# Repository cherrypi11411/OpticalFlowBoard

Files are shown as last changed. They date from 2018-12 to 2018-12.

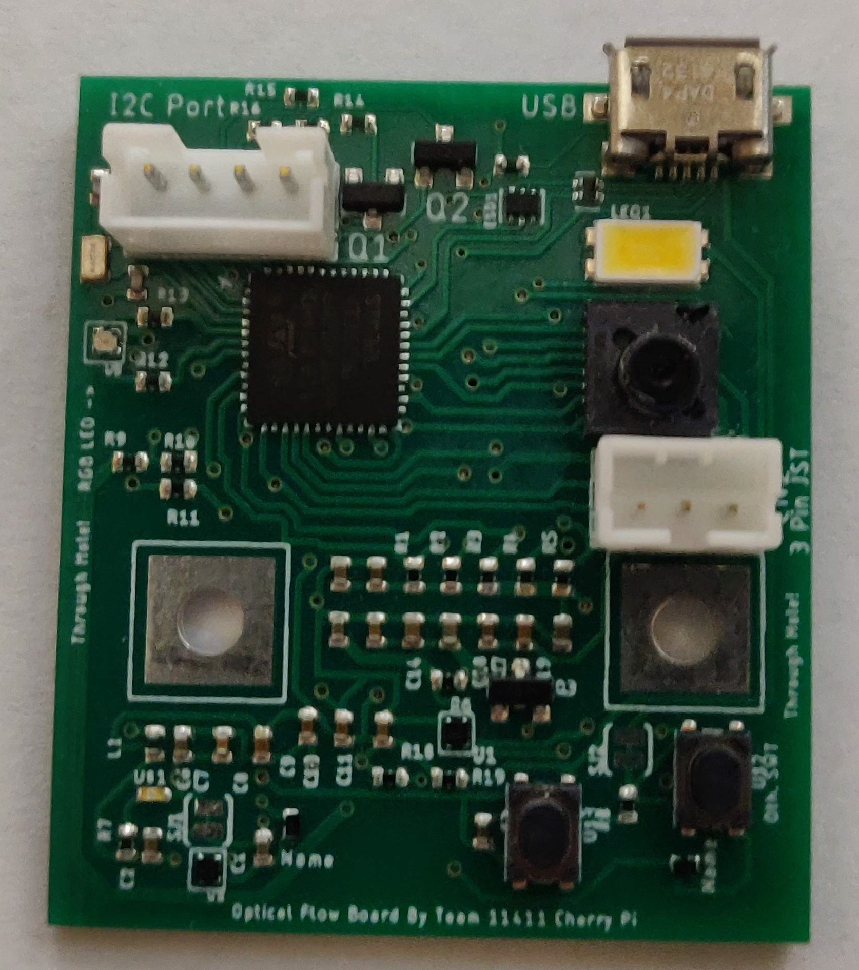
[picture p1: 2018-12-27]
documentation/Board-1-Front.jpg

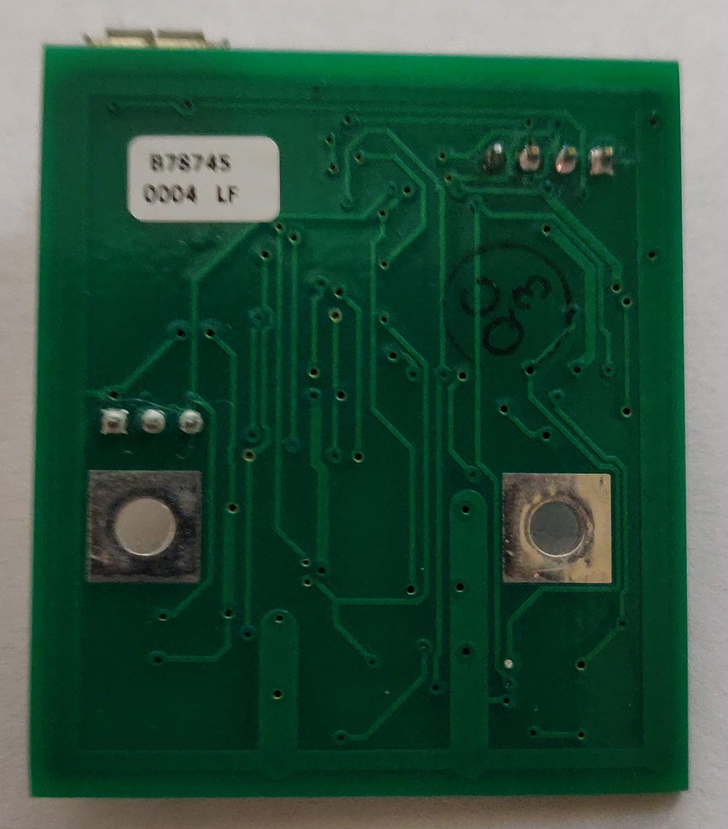
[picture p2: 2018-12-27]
documentation/Board-2-Back.jpg

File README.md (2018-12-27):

# OpticalFlowBoard
Hardware design and source code for OpticalFlowBoard

We are [Team 11411 Cherry Pi](https://cherrypi.egoslike.us/). We are a FIRST Tech Challenge (FTC) robotics team based in San Diego, California. Over the past several years, one of the biggest challenges we see with the robots is how to determine where the robot is accurately. During our journey, we discovered many ways to approach this problem. One that looked especially promising is using an optical flow sensor similar to what is available for many optical mice. One such product is produced by PixArt, the [PMW-3901 chip](http://www.pixart.com.tw/product_data.asp?product_id=168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).

This chip is especially attractive as it is designed for robotics/drone usage with the sensor at a distance from the surface. Many mice sensors require a very close distance to surfaces to operate properly. A big disadvantage of this chip for our purposes is that it uses SPI for communication. Within FTC, SPI is not an option for sensor integration. Instead, analog, digital or I2C sensors are allowed.

We then experimented with translating SPI to I2C and created a prototype using these two products:
* The [Butterfly Board](https://www.tindie.com/products/TleraCorp/butterfly-stm32l433-development-board/)
* The [PMW-3901 Sensor Board](https://www.tindie.com/products/onehorse/pmw3901-optical-flow-sensor/)

These products are open source designs so inspired by those designs, some of our students created a new design combining the two boards together into a unified product. We then investigated getting the boards manufactured and eventually got in contact with [Advanced Assembly](http://www.aapcb.com/). When we described our project to them and that this board was being designed and programmed by middle and high school age kids, they were excited to help us out and graciously provided feedback on our design as well as offering to manufacture an initial run of boards for prototyping for free to us.

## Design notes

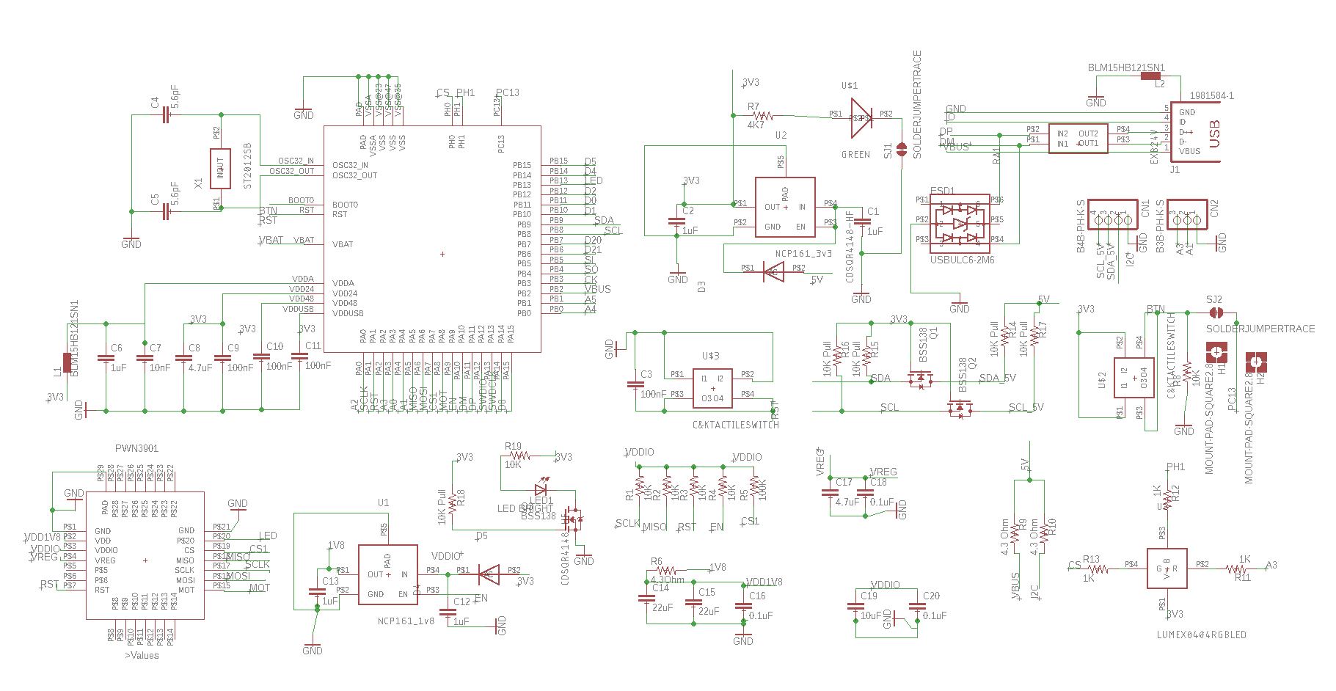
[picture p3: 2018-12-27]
documentation/Schematic.png

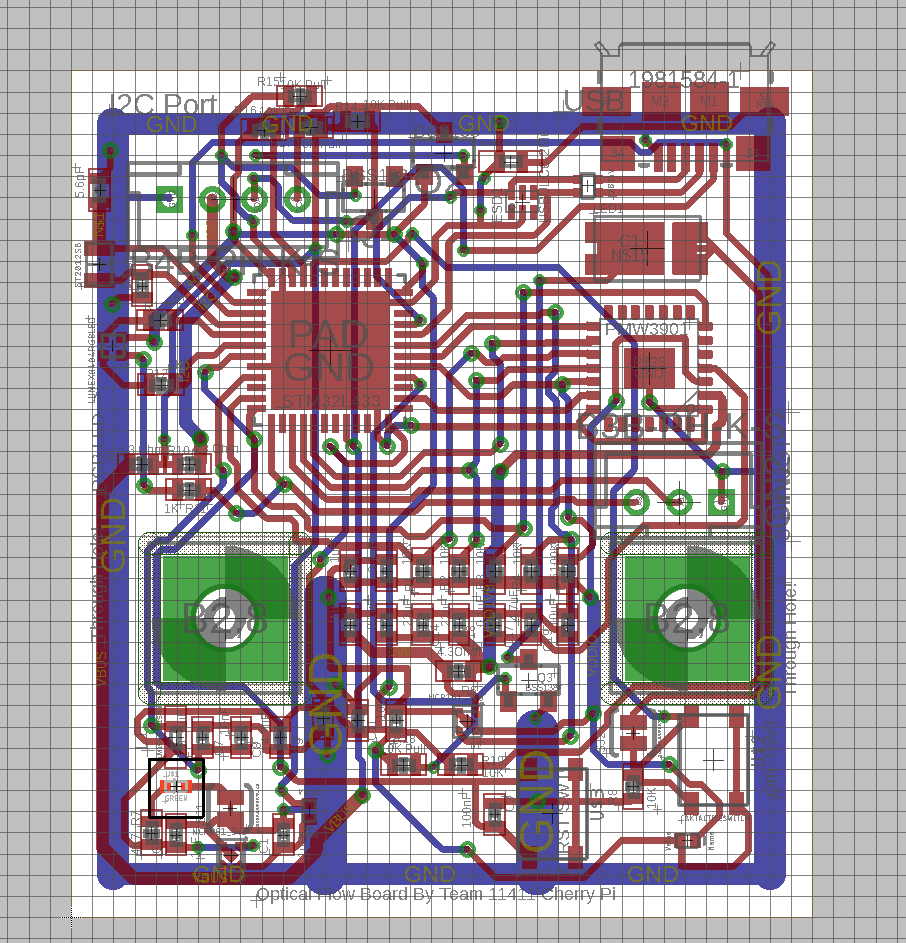
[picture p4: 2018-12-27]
documentation/Layout.png

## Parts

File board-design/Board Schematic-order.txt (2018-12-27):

Exported from EAGLE with DesignLink
Parts List:

Quantity	Value	Package	Order code	Manufacturer	Manuf. Code	Availability	Price (from)	Description
5        	1uF		0402-CAP	46P6240		MC0805B104K500A5.08MM	589108	0.085	MULTICOMP - MC0805B104K500A5.08MM - CERAMIC CAPACITOR 0.1UF, 50V, X7R, 10%, RADIAL
4			100nF	0402-CAP	URL: https://www.mouser.com/ProductDetail/KEMET/C0402C104K4RACAUTO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
2			5.6pF	0402-CAP	URL: https://www.mouser.com/ProductDetail/KEMET/C0402C569D5GACAUTO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
1			10uF	0402-CAP	53W3840		EEE-1VA100WR	45488	0.081	PANASONIC ELECTRONIC COMPONENTS - EEE-1VA100WR - ALUMINUM ELECTROLYTIC CAPACITOR, 10UF, 35V, 20%, SMD
1			10 nF	0402-CAP	URL: https://www.mouser.com/ProductDetail/KEMET/C0402C103K4RALTU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
2			4.7uF	0402-CAP	27X7920		293D475X9016B2TE3	20000	0.137	VISHAY - 293D475X9016B2TE3 - TANTALUM CAPACITOR, 4.7UF 16V 2.9 OHM 10%, 3528-21, FULL REEL
2			22uF	0402-CAP	53W3820		EEE-1HA220WP	5254	0.133	PANASONIC ELECTRONIC COMPONENTS - EEE-1HA220WP - ALUMINUM ELECTROLYTIC CAPACITOR, 22UF, 50V, 20%, SMD
3			0.1uF	0402-CAP	46P6240		MC0805B104K500A5.08MM	589108	0.085	MULTICOMP - MC0805B104K500A5.08MM - CERAMIC CAPACITOR 0.1UF, 50V, X7R, 10%, RADIAL
1			B4B-PH-K-S	37K9958	FARNELL	B4B-PH-K-S(LF)(SN)	4851	0.115	JST (JAPAN SOLDERLESS TERMINALS) - B4B-PH-K-S(LF)(SN) - WIRE TO BOARD CONNECTOR, HEADER, 4 POSITION, 2MM
2			CDSQR4148-HF	CDSQR4148-HF	URL:			https://www.digikey.com/product-detail/en/comchip-technology/CDSQR4148-HF/641-1677-1-ND/5147314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	
1			USBULC6-2M6				URL:https://www.digikey.com/product-detail/en/stmicroelectronics/USBULC6-2M6/497-7044-1-ND/1880382
2			MOUNT-PAD-SQUARE2.8	2,8-PAD-SQUARE	unknown					N/A
1			1981584-1	1981584-1	74M6302		1981584-1	13	1.08	AMP - TE CONNECTIVITY - 1981584-1 - MICRO USB CONN, 2.0 TYPE AB, RCPT, SMT
2			BLM15HB121SN1	0402	73M9043		BLM15HB121SN1D	0	0.061	MURATA - BLM15HB121SN1D - FERRITE BEAD, 0.7OHM, 300mA, 0402
1			PMW3901	COB	unknown		Provided			
6			10K	0402-RES	01X1282		ERA-3AEB103V	15000	0.038	PANASONIC ELECTRONIC COMPONENTS - ERA-3AEB103V - RES, METAL FILM, 10K, 0.1%, 0.1W, 0603, REEL
1			100K	0402-RES	01P2083		MCTF0805BTC1003	7622	0.098	MULTICOMP - MCTF0805BTC1003 - RES, THIN FILM, 100K, 0.1%, 0.1W, 0805
3			0402RES.KW	0402-RES	13AC1056		CRCW04024R30FKED	9980	0.018	VISHAY - CRCW04024R30FKED - RES, AEC-Q200, THICK FILM, 4R3, 1%, 0402
1			4K7	0402-RES	90W3200		ERJ-3EKF4701V	65000	0.0080	PANASONIC ELECTRONIC COMPONENTS - ERJ-3EKF4701V - RES, THICK FILM, 4K7, 1%, 0.1W, 0603, REEL
3			1K	URL: https://www.mouser.com/ProductDetail/Panasonic/ERJ-S02F1001X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
1			EXB24V	EXB24V	52W4404		EXB-24V100JX	0	0.01	PANASONIC ELECTRONIC COMPONENTS - EXB-24V100JX - 10ohm, 7 inch reel
2			SOLDERJUMPERTRACE	SJ_2S-TRACE	unknown		N/A			
1			GREEN	0402LED	30K1434	DIALIGHT	551-0207F	46775	0.361	DIALIGHT - 551-0207F - INDICATOR, LED PCB, 3MM, GREEN, 2.1V
1			LUMEX RGB LED	URL: https://www.mouser.com/new/lumex/lumexrgb0404/
2			C&KTACTILESWITCH	C&KTACTILESWITCH	URL:					https://www.mouser.com/ProductDetail/CK/PTS810SJS250SMTRLFS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
1			STM32L433	QFN50P700X700X60-49N	24AC5432		STM32L433CCU6	624	3.57	STMICROELECTRONICS - STM32L433CCU6 - MCU, ARM CORTEX-M4, 80MHZ, QFN-48 Provided
1			NCP161	NCP161	42AC1775		NCP161AMX330TBG	5948	0.111	ON SEMICONDUCTOR - NCP161AMX330TBG - LDO, FIXED, 3.3V, 0.45A, XDFN-4
1			NCP161	NCP161			NCP161AMX180TBG	5948	0.111	ON SEMICONDUCTOR - NCP161AMX180TBG - LDO, FIXED, 1.8V, 0.45A, XDFN-4
1			ST2012SB	ST2012SB	38Y8580		ST2012SB32768H5HPWAA	910	0.553	AVX - ST2012SB32768H5HPWAA - CRYSTAL, 32.768KHZ, 12.5PF, 2 X 1.2MM
1			B3B-PH-K-S URL: https://www.digikey.com/product-detail/en/jst-sales-america-inc/B3B-PH-K-S-LF-SN/455-1705-ND/926612
5			PRT-14491 (10k Pull) URL: https://www.robotshop.com/en/resistor-10k-ohm-1-4-watt-pth-20pk.html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
3			BSS138 URL: https://www.digikey.com/product-detail/en/fairchild-semiconductor/BSS138/BSS138CT-ND/244294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
1			LED BRIGHT URL: https://www.digikey.com/product-detail/en/samsung-semiconductor-inc/SPMWHT541ML5XAR0S6/1510-2182-1-ND/6569493

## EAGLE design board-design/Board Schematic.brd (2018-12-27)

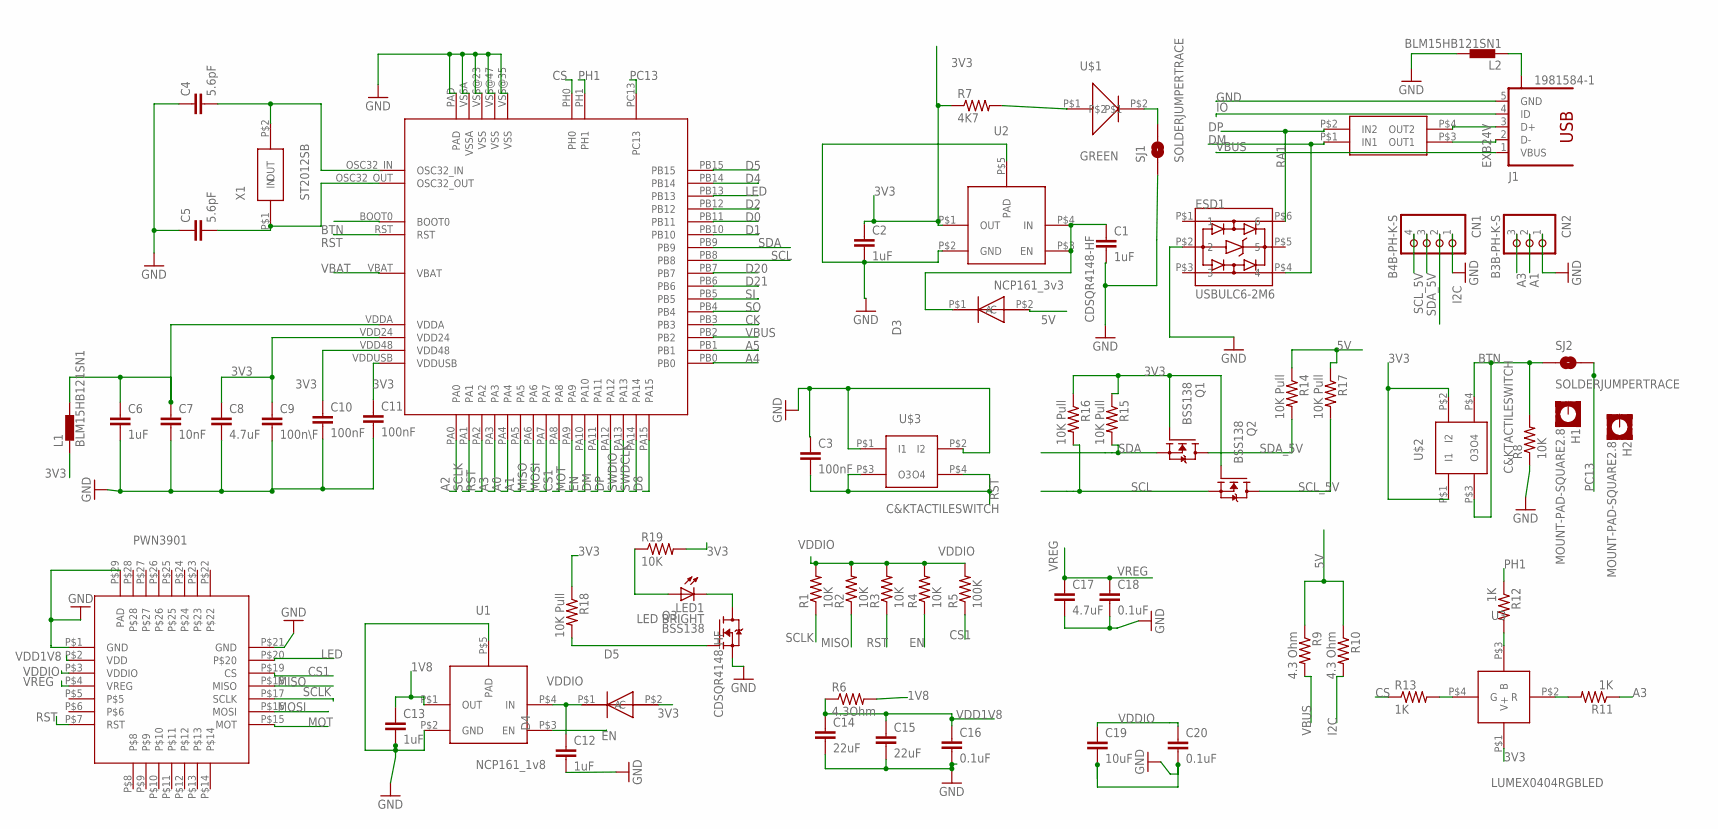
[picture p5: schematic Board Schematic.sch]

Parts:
C1, C2, C6, C12, C13: 1uF; 0402-CAP
C3, C10, C11: 100nF; 0402-CAP
C4, C5: 5.6pF; 0402-CAP
C7: 10nF; 0402-CAP
C8, C17: 4.7uF; 0402-CAP
C9: 100n\F; 0402-CAP
C14, C15: 22uF; 0402-CAP
C16, C18, C20: 0.1uF; 0402-CAP
C19: 10uF; 0402-CAP
CN1: B4B-PH-K-S
CN2: B3B-PH-K-S
D3, D4: CDSQR4148-HF
ESD1: USBULC6-2M6; UQFN6
H1, H2: MOUNT-PAD-SQUARE2.8; 2,8-PAD-SQUARE
J1: 1981584-1
L1, L2: BLM15HB121SN1; 0402
LED1: LED BRIGHT; LM561C
PWN3901: COB_PMW3901; COB
Q1, Q2, Q3: BSS138; SOT23
R1, R2, R3, R4, R8, R19: 10K; 0402-RES
R5: 100K; 0402-RES
R6: 4.3Ohm; 0402-RES
R7: 4K7; 0402-RES
R9, R10: 4.3 Ohm; 0402-RES
R11, R12, R13: 1K; 0402-RES
R14, R15, R16, R17, R18: 10K Pull; 0402-RES
RA1: EXB24V
SJ1, SJ2: SOLDERJUMPERTRACE; SJ_2S-TRACE
U1: NCP161_1v8; NCP161
U2: NCP161_3v3; NCP161
U3: LUMEX0404RGBLED; LX0404
U$1: GREEN; 0402LED
U$2, U$3: C&KTACTILESWITCH
U$4: STM32L433; QFN50P700X700X60-49N
X1: ST2012SB

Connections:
1V8: C13.1, R6.2, U1.P$1 (OUT)
3V3: C2.1, C8.1, C9.1, C10.1, C11.1, D4.P$2 (A), L1.1, Q1.1 (G), Q2.1 (G), R7.1, R15.1, R16.1, R18.1, R19.2, U2.P$1 (OUT), U3.P$1 (V+), U$2.P$1 (I1), U$2.P$2 (I2), U$4.VDD24, U$4.VDD48, U$4.VDDUSB
5V: D3.P$2 (A), R9.1, R10.1, R14.1, R17.1
A0: U$4.PA4
A1: CN2.2, U$4.PA5
A2: U$4.PA0
A3: CN2.3, R11.1, U$4.PA3
A4: U$4.PB0
A5: U$4.PB1
BTN: R8.2, SJ2.1, U$2.P$3 (O3), U$2.P$4 (O4), U$4.BOOT0
CK: U$4.PB3
CS: R13.1, U$4.PH0
CS1: PWN3901.P$19 (CS), R5.1, U$4.PA8
D0: U$4.PB11
D1: U$4.PB10
D2: U$4.PB12
D4: U$4.PB14
D5: Q3.1 (G), R18.2, U$4.PB15
D8: U$4.PA15
D20: U$4.PB7
D21: U$4.PB6
DM: ESD1.P$4 (4), RA1.P$1 (IN1), U$4.PA11
DP: ESD1.P$6 (6), RA1.P$2 (IN2), U$4.PA12
EN: R4.1, U1.P$3 (EN), U$4.PA10
GND: C1.2, C2.2, C3.1, C4.1, C5.1, C6.2, C7.2, C8.2, C9.2, C10.2, C11.2, C12.2, C13.2, C14.2, C15.2, C16.2, C17.2, C18.2, C19.2, C20.2, CN1.1, CN2.1, ESD1.P$2 (2), J1.5 (GND), L2.2, PWN3901.P$1 (GND), PWN3901.P$21 (GND), PWN3901.P$29 (PAD), Q3.2 (S), R8.1, SJ1.1, U1.P$2 (GND), U1.P$5 (PAD), U2.P$2 (GND), U2.P$5 (PAD), U$3.P$1 (I1), U$3.P$2 (I2), U$4.PAD, U$4.VSS@23 (VSS), U$4.VSS@35 (VSS), U$4.VSS@47 (VSS), U$4.VSSA
I2C: CN1.2, R10.2
IO: J1.4 (ID)
LED: PWN3901.P$20, U$4.PB13
MISO: PWN3901.P$18 (MISO), R2.1, U$4.PA6
MOSI: PWN3901.P$16 (MOSI), U$4.PA7
MOT: PWN3901.P$15 (MOT), U$4.PA9
unnamed: C4.2, U$4.OSC32_IN, X1.P$2 (OUT)
unnamed: C6.1, C7.1, L1.2, U$4.VDDA
unnamed: R13.2, U3.P$4 (G)
unnamed: C5.2, U$4.OSC32_OUT, X1.P$1 (IN)
unnamed: R12.2, U3.P$3 (B)
unnamed: R11.2, U3.P$2 (R)
unnamed: J1.S1, L2.1
unnamed: J1.3 (D+), RA1.P$4 (OUT2)
unnamed: J1.2 (D-), RA1.P$3 (OUT1)
unnamed: R7.2, U$1.P$1
unnamed: SJ1.2, U$1.P$2
unnamed: LED1.A1 (A), LED1.A2 (A), LED1.A3 (A), R19.1
unnamed: LED1.C1 (C), LED1.C2 (C), LED1.C3 (C), Q3.3 (D)
unnamed: C1.1, D3.P$1 (C), U2.P$3 (EN), U2.P$4 (IN)
PC13: SJ2.2, U$4.PC13
PH1: R12.1, U$4.PH1
RST: C3.2, PWN3901.P$7 (RST), R3.1, U$3.P$3 (O3), U$3.P$4 (O4), U$4.PA2, U$4.RST
SCL: Q2.2 (S), R16.2, U$4.PB8
SCLK: PWN3901.P$17 (SCLK), R1.1, U$4.PA1
SCL_5V: CN1.4, Q2.3 (D), R17.2
SDA: Q1.2 (S), R15.2, U$4.PB9
SDA_5V: CN1.3, Q1.3 (D), R14.2
SI: U$4.PB5
SO: U$4.PB4
SWDCLK: U$4.PA14
SWDIO: U$4.PA13
VBAT: U$4.VBAT
VBUS: J1.1 (VBUS), R9.2, U$4.PB2
VDD1V8: C14.1, C15.1, C16.1, PWN3901.P$2 (VDD), R6.1
VDDIO: C12.1, C19.1, C20.1, D4.P$1 (C), PWN3901.P$3 (VDDIO), R1.2, R2.2, R3.2, R4.2, R5.2, U1.P$4 (IN)
VREG: C17.1, C18.1, PWN3901.P$4 (VREG)

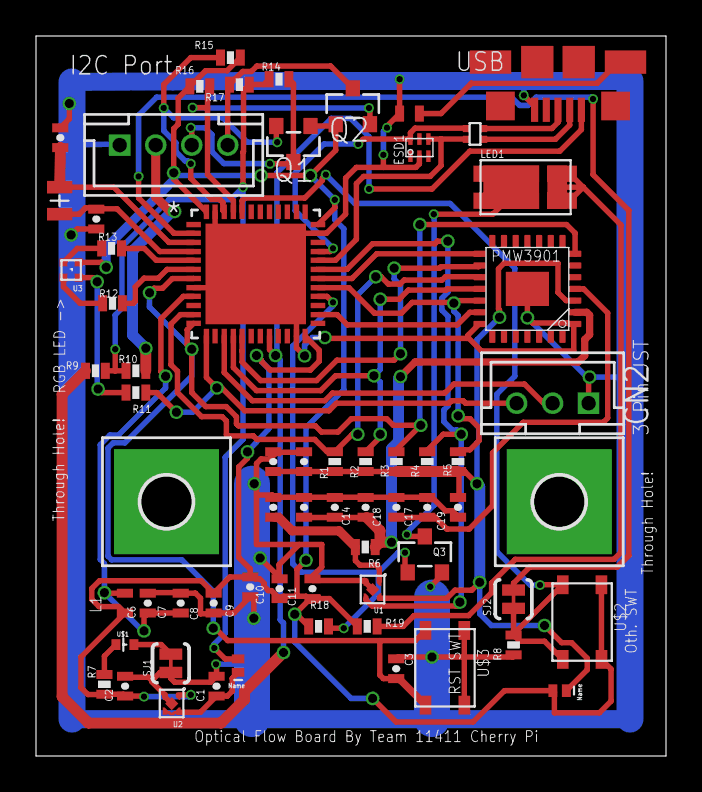
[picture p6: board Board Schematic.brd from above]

Board: 2 copper layers, 35.0 x 40.0 mm, 65 parts (0 on the bottom side), 44 nets.

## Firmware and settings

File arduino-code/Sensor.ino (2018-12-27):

#include <EEPROM.h>

#include "WireSlave.h"
#include "PMW3901.h"
#include "CCITTCrc16.h"
#include "stm32l4_wiring_private.h"
#include <limits.h>

#define  SLAVE_ADDRESS            0x29  //slave address,any number from 0x01 to 0x7F

#define PRODUCT_ID_CMD            0x00
#define REVISION_ID_CMD           0x01

#define CP_PRODUCT_ID_CMD         0x20
#define CP_REVISION_ID_CMD        0x21
#define SPI_PASSTHRU_CMD          0x22
#define LEDSTATUS_CMD             0x23
#define READ_RELATIVE_CMD         0x24
#define REREAD_RELATIVE_CMD       0x25
#define ZERO_ABSOLUTE_CMD         0x26
#define READ_ABSOLUTE_CMD         0x27
#define RESET_CMD                 0x28
#define CHANGE_I2C_ADDRESS_CMD    0x29

#define CP_PRODUCT_ID             0x42
#define CP_REVISION_ID            0x00


#define RED_LED           17
#define GREEN_LED         38
#define BLUE_LED          26
#define WHITE_LED         5

// External LED control pin (active low)
#define PMW_LED           3
#define J3_OUTPUT1        5
#define J3_OUTPUT2        15
#define BUTTON            39

// Motion interrupt (active low)
#define MOTION_INTERRUPT  30

#define LED_ON    LOW
#define LED_OFF   HIGH


#define STATE_WAITING_FOR_REGISTER      1
#define STATE_WAITING_FOR_DATA          2
#define STATE_WAITING_FOR_READ          3
#define STATE_WAITING_FOR_READ_OR_DATA  4

int i2cState = STATE_WAITING_FOR_REGISTER;

/********* Global  Variables  ***********/

struct Config {
  uint16_t  slaveAddress;
  uint8_t   debugOn;
};

struct EEPROM_Config {
  Config settings;
  uint16_t crc;
};

uint8_t productId;
uint8_t revisionId;

PMW3901 sensor(10);
CCITTCrc16 crcCalculator;

Config settings;


void defaultConfig() {
  settings.slaveAddress = SLAVE_ADDRESS;
  settings.debugOn = 0x00;
}

void loadConfig() {
  EEPROM_Config config;
  EEPROM.get(0, config);

  uint16_t crc = crcCalculator.calculate((char *)(&config.settings), sizeof(Config));

  if (crc != config.crc) {
    Serial.print("Saved settings invalid - using defaults ");
    Serial.print(config.crc);
    Serial.print(" <> ");
    Serial.println(crc);
    defaultConfig();
  } else {
    settings = config.settings;
  }
}

void saveConfig() {
  EEPROM_Config oldConfig;
  EEPROM_Config config;
  config.settings = settings;
  config.crc = crcCalculator.calculate((char *)(&config.settings), sizeof(Config));

  EEPROM.get(0, oldConfig);
  if (memcmp(&oldConfig, &config, sizeof(config) != 0)) {
    EEPROM.put(0, config);
  }
}

String inputBuffer = "";
bool inputComplete = false;

void setup()
{
  pinMode(BUTTON, INPUT);

  // Set the pins to output mode
  pinMode(J3_OUTPUT1, OUTPUT);
  digitalWrite(J3_OUTPUT1, LOW);
  pinMode(J3_OUTPUT2, OUTPUT);
  digitalWrite(J3_OUTPUT2, HIGH);
  pinMode(RED_LED, OUTPUT);
  digitalWrite(RED_LED, LED_OFF);
  pinMode(GREEN_LED, OUTPUT);
  digitalWrite(GREEN_LED, LED_OFF);
  pinMode(BLUE_LED, OUTPUT);
  digitalWrite(BLUE_LED, LED_OFF);
  pinMode(WHITE_LED, OUTPUT);
  digitalWrite(WHITE_LED, LED_OFF);

  inputBuffer.reserve(200);
  
  // Set up the serial communications over the USB connector
  Serial.begin(9600);

  loadConfig();

  delay(1000);

  Serial.println("Initalizing");

  delay(1000);

  if (digitalRead(BUTTON) == HIGH) {
    settings.slaveAddress = SLAVE_ADDRESS;
    settings.debugOn = 0x00;
    Serial.print("Resetting config slave address ");
    Serial.println(settings.slaveAddress, HEX);
    saveConfig();
    for (int i = 0; i < 10; i++) {
      digitalWrite(BLUE_LED, LED_OFF);
      digitalWrite(RED_LED, LED_ON);
      delay(50);
      digitalWrite(RED_LED, LED_OFF);
      digitalWrite(GREEN_LED, LED_ON);
      delay(50);
      digitalWrite(GREEN_LED, LED_OFF);
      digitalWrite(BLUE_LED, LED_ON);
      delay(50);
    }
    digitalWrite(BLUE_LED, LED_OFF);
  }
  
  // Set up the I2C communication callbacks
  WireSlave.onOverrideHandler(ll_callback);
  WireSlave.onRequest(requestEvent);
  WireSlave.onReceive(receiveEvent);

  Serial.print("Starting slave listen on ");
  Serial.println(settings.slaveAddress, HEX);

  // Start listening as a slave
  WireSlave.begin(settings.slaveAddress);

  Serial.println("Starting sensor");
  // start up processing for the optical flow chip
  sensor.begin();
  Serial.println("Reading product id");
  productId = sensor.registerRead(PRODUCT_ID_CMD);
  Serial.println("Reading revision id");
  revisionId = sensor.registerRead(REVISION_ID_CMD);

  // write out some diagnostics
  Serial.print("Init completed productId = ");
  Serial.print(productId, HEX);
  Serial.print(" revisionId = ");
  Serial.println(revisionId, HEX);
}

uint8_t lastValue;
bool lastValueSet = false;
uint16_t heartbeat = 0;
bool ledOverwritten = false;

typedef struct __attribute__((packed)) _RelativeRead
{
  uint32_t timestamp;
  int16_t xOffset;
  int16_t yOffset;
  uint16_t crc;
  uint8_t overflow;

  void incrementOverflowX()
  {
    uint8_t value = overflow & 0x0f;
    value++;
    overflow = (overflow & 0xf0) | (value & 0x0f);
  }

  void incrementOverflowY()
  {
    uint8_t value = (overflow & 0xf0) >> 4;
    value++;
    overflow = (overflow & 0x0f) | ((value & 0xf0) << 4);
  }

  void calcCrc()
  {
    char * me = (char *)this;
    crc = crcCalculator.calculate(me, sizeof(uint32_t) + sizeof(int16_t) + sizeof(int16_t) + sizeof(uint8_t));
  }
} RelativeRead;

typedef struct __attribute__((packed)) _AbsoluteRead
{
  uint32_t timestamp;
  int32_t x;
  int32_t y;
  uint16_t crc;

  void calcCrc()
  {
    char * me = (char *)this;
    crc = crcCalculator.calculate(me, sizeof(uint32_t) + sizeof(int32_t) + sizeof(int32_t));
  }

  void reset() {
    timestamp = x = y = crc = 0;
  }
} AbsoluteRead;

RelativeRead last = { 0 };
RelativeRead cached = { 0 };

AbsoluteRead absolute = { 0 };

uint8_t ledStatus = 0;

int32_t callbackCount = 0;
int32_t requestCount = 0;
int32_t receiveCount = 0;
int32_t readyCount = 0;
int32_t addressMatchSlaveTransmitCount = 0;
int32_t addressMatchSlaveReceiveCount = 0;

void loop() {
  if (lastValueSet)
  {
    Serial.print("    ");
    Serial.println(lastValue, HEX);
    lastValueSet = false;
  }
  heartbeat++;


  if (!ledOverwritten)
  {
    switch (heartbeat)
    {
      case 100:
        digitalWrite(RED_LED, LED_ON);
        digitalWrite(GREEN_LED, LED_OFF);
        digitalWrite(BLUE_LED, LED_OFF);
        break;
      case 200:
        digitalWrite(RED_LED, LED_ON);
        digitalWrite(GREEN_LED, LED_ON);
        digitalWrite(BLUE_LED, LED_OFF);
        break;
      case 300:
        digitalWrite(RED_LED, LED_OFF);
        digitalWrite(GREEN_LED, LED_ON);
        digitalWrite(BLUE_LED, LED_OFF);
        break;
      case 400:
        digitalWrite(RED_LED, LED_OFF);
        digitalWrite(GREEN_LED, LED_ON);
        digitalWrite(BLUE_LED, LED_ON);
        break;
      case 500:
        digitalWrite(RED_LED, LED_OFF);
        digitalWrite(GREEN_LED, LED_OFF);
        digitalWrite(BLUE_LED, LED_ON);
        break;
      case 600:
        digitalWrite(RED_LED, LED_ON);
        digitalWrite(GREEN_LED, LED_OFF);
        digitalWrite(BLUE_LED, LED_ON);
        break;
      case 700:
        digitalWrite(RED_LED, LED_ON);
        digitalWrite(GREEN_LED, LED_ON);
        digitalWrite(BLUE_LED, LED_ON);
        break;
      case 800:
        digitalWrite(RED_LED, LED_OFF);
        digitalWrite(GREEN_LED, LED_OFF);
        digitalWrite(BLUE_LED, LED_OFF);
        break;
    }
  }
  if ((heartbeat % 100 == 0) && settings.debugOn)
  {
    Serial.print("Button = ");
    Serial.println(digitalRead(BUTTON) == HIGH ? "HIGH" : "LOW");
    Serial.print("Counts: ");
    Serial.print(callbackCount);
    Serial.print("/");
    Serial.print(requestCount);
    Serial.print("/");
    Serial.print(receiveCount);
    Serial.print("/");
    Serial.print(readyCount);
    Serial.print("/");
    Serial.print(addressMatchSlaveTransmitCount);
    Serial.print("/");
    Serial.print(addressMatchSlaveReceiveCount);
    Serial.print("/");
    Serial.print(absolute.x);
    Serial.print("/");
    Serial.print(absolute.y);
    Serial.print("/");
    Serial.print(absolute.timestamp);
    Serial.print("/");
    Serial.print(SYSCFG->CFGR1, HEX);
    Serial.print("/");
    Serial.print(WireSlave.get_cr1(), HEX);
    Serial.print("/");
    Serial.print(WireSlave.get_cr2(), HEX);
    Serial.print("/");
    Serial.print(WireSlave.get_oar1(), HEX);
    Serial.print("/");
    Serial.print(WireSlave.get_isr(), HEX);
    Serial.print("/");
    Serial.print(WireSlave.get_sda_pin());
    Serial.print("/");
    Serial.print(WireSlave.get_scl_pin());
    Serial.println("<<<");
  }
  if (heartbeat == 800) {
    heartbeat = 0;
  }

  // Retrieve the values from the optical flow chip
  sensor.registerRead(0x02);
  int16_t deltaX = ((int16_t)sensor.registerRead(0x04) << 8) | sensor.registerRead(0x03);
  int16_t deltaY = ((int16_t)sensor.registerRead(0x06) << 8) | sensor.registerRead(0x05);

  // check for overflow
  if (checked_add_16(deltaX, last.xOffset, &(last.xOffset)))
  {
    last.incrementOverflowX();
  }
  if (checked_add_16(deltaY, last.yOffset, &(last.yOffset)))
  {
    last.incrementOverflowY();
  }

  absolute.x += deltaX;
  absolute.y += deltaY;

  absolute.timestamp = last.timestamp = micros();

  if (inputComplete) {
    if (inputBuffer[0] == 'a') {
      uint8_t high = getHexDigit(inputBuffer[1]);
      uint8_t low = getHexDigit(inputBuffer[2]);
      if (high == 255 || low == 255) {
        Serial.println("Invalid hex address");
      } else {
        settings.slaveAddress = (high << 4 | low) & 0x7f;
        Serial.print("Changing slave address to ");
        Serial.println(settings.slaveAddress, HEX);
        saveConfig();
      }
    } else if (inputBuffer[0] == 'd') {
      settings.debugOn = inputBuffer[1] == '1';
      Serial.print("Debug ");
      Serial.println(settings.debugOn ? "on" : "off");
      saveConfig();
    }
    inputComplete = false;
  }

  delay(50);
}

uint8_t getHexDigit(char value) {
  switch (value) {
    case '0': case '1': case '2': case '3': case '4':
    case '5': case '6': case '7': case '8': case '9':
      return (uint8_t)(value - '0');
    case 'a': case 'b': case 'c': case 'd': case 'e': case 'f':
      return (uint8_t)(value - 'a' + 10);
    case 'A': case 'B': case 'C': case 'D': case 'E': case 'F':
      return (uint8_t)(value - 'A' + 10);
  }

  return 255;
}

void serialEvent() {
  while (Serial.available()) {
    char inChar = (char)Serial.read();
    inputBuffer += inChar;
    if (inChar == '\n') {
      inputComplete = true;
    }
  }
}

bool checked_add_32(int32_t a, int32_t b, int32_t *rp) {
  if (b > 0 && a > INT_MAX - b) {
    *rp =  (a + INT_MIN) + (b + INT_MIN);
    return true;
  }
  if (b < 0 && a < INT_MIN - b) {
    *rp =  (a - INT_MIN) + (b - INT_MIN);
    return true;
  }
  *rp = a + b;
  return false;
}

bool checked_add_16(int16_t a, int16_t b, int16_t *rp) {
  if (b > 0 && a > SHRT_MAX - b) {
    *rp =  (a + SHRT_MIN) + (b + SHRT_MIN);
    return true;
  }
  if (b < 0 && a < SHRT_MIN - b) {
    *rp =  (a - SHRT_MIN) + (b - SHRT_MIN);
    return true;
  }
  *rp = a + b;
  return false;
}

uint8_t lastRegister;
uint8_t cachedValue;
bool cacheStale = true;

uint8_t cachedBuffer[20];
uint8_t cachedBufferCount = 0;
uint8_t *cachedBufferPtr = cachedBuffer;

void(* resetFunc) (void) = 0;

extern const stm32l4_i2c_pins_t g_WirePins;

void dumpState(const char * message)
{
  if (!settings.debugOn) {
    return;
  }
  Serial.println(message);
  Serial.print("    State:");
  Serial.print(WireSlave.state(), HEX);
  //Serial.print(" events:");
  //Serial.print(WireSlave.get_events(), HEX);
  //Serial.print(" xf:");
  //Serial.print(WireSlave.xf_count());
  //Serial.print(" tx:");
  //Serial.print(WireSlave.tx_count());
  Serial.print(" CR1:");
  Serial.print(WireSlave.get_cr1(), HEX);
  //Serial.print(" CR2:");
  //Serial.print(WireSlave.get_cr2(), HEX);
  Serial.print(" ISR:");
  Serial.print(WireSlave.get_isr(), HEX);
  //Serial.print(" ICR:");
  //Serial.print(WireSlave.get_icr(), HEX);
  //Serial.print(" scl-GPIO:");
  //Serial.print(stm32l4_gpio_pin_read_configure(g_WirePins.scl), HEX);
  //Serial.print(" sda-GPIO:");
  //Serial.println(stm32l4_gpio_pin_read_configure(g_WirePins.sda), HEX);
  Serial.println();
}



void ll_callback(struct _stm32l4_i2c_t *i2c)
{
  callbackCount++;

  I2C_TypeDef * I2C = i2c->I2C;
  uint32_t i2c_isr = I2C->ISR;

  if (i2c->state == I2C_STATE_READY)
  {
    readyCount++;
    if (i2c_isr & I2C_ISR_ADDR)
    {
      if (i2c_isr & I2C_ISR_DIR)
      {
        addressMatchSlaveTransmitCount++;
        
        dumpState("Address match, slave transmit");
        I2C->CR1 |= (I2C_CR1_TXIE | I2C_CR1_NACKIE | I2C_CR1_STOPIE);
        I2C->ISR |= I2C_ISR_TXE;
        I2C->ICR = I2C_ICR_ADDRCF;
        i2c->state = I2C_STATE_SLAVE_TRANSMIT;
      }
      else
      {
        addressMatchSlaveReceiveCount++;

        dumpState("Address match, slave receive");
        I2C->CR1 |= (I2C_CR1_RXIE | I2C_CR1_STOPIE);
        I2C->ICR = I2C_ICR_ADDRCF;
        i2c->state = I2C_STATE_SLAVE_RECEIVE;
      }
    }
  }
  else if (i2c->state == I2C_STATE_SLAVE_RECEIVE)
  {
    if (i2c_isr & I2C_ISR_RXNE)
    {
      if (i2cState == STATE_WAITING_FOR_REGISTER || i2cState == STATE_WAITING_FOR_READ) {
        debugPrint("Receive data ");
        lastRegister = I2C->RXDR;
        debugPrintln(lastRegister, HEX);
        cacheStale = true;
        i2cState = determineStateFromRegisterReceive(lastRegister);
      } else if (i2cState == STATE_WAITING_FOR_DATA || i2cState == STATE_WAITING_FOR_READ_OR_DATA) {
        uint8_t data = I2C->RXDR;
        switch (lastRegister) {
          case LEDSTATUS_CMD:
            setLEDStatus(data);
            i2cState = STATE_WAITING_FOR_REGISTER;
            break;
          case ZERO_ABSOLUTE_CMD:
            // We don't care about the data, just zero out the absolute data
            absolute.reset();
            i2cState = STATE_WAITING_FOR_REGISTER;
            break;
          case RESET_CMD:
            if (data == 0) {
              Serial.println("Debug off");
              settings.debugOn = 0;
              saveConfig();
            } else if (data == 1) {
              Serial.println("Debug on");
              settings.debugOn = 1;
              saveConfig();
            }
            resetFunc();
            i2cState = STATE_WAITING_FOR_REGISTER;
            break;
          case CHANGE_I2C_ADDRESS_CMD:
            settings.slaveAddress = data & 0x7f;
            Serial.print("Changing slave address to ");
            Serial.println(settings.slaveAddress, HEX);
            saveConfig();
            break;
          default:
            i2cState = STATE_WAITING_FOR_REGISTER;
            break;
        }
      }
    }
    else
    {
      if (i2c_isr & I2C_ISR_ADDR)
      {
        dumpState("Receive terminated by address match; repeated start");
        I2C->CR1 &= ~(I2C_CR1_RXIE | I2C_CR1_STOPIE);
        if (i2c_isr & I2C_ISR_DIR)
        {
          debugPrintln("Address match, slave transmit");
          I2C->CR1 |= (I2C_CR1_TXIE | I2C_CR1_NACKIE | I2C_CR1_STOPIE);
          I2C->ISR |= I2C_ISR_TXE;
          I2C->ICR = I2C_ICR_ADDRCF;
          i2c->state = I2C_STATE_SLAVE_TRANSMIT;
        }
        else
        {
          debugPrintln("Address match, slave receive");
          I2C->CR1 |= (I2C_CR1_RXIE | I2C_CR1_STOPIE);
          I2C->ICR = I2C_ICR_ADDRCF;
          i2c->state = I2C_STATE_SLAVE_RECEIVE;
        }
      }
      else if (i2c_isr & I2C_ISR_STOPF)
      {
        dumpState("Received terminated by stop");
        I2C->CR1 &= ~(I2C_CR1_RXIE | I2C_CR1_STOPIE);
        I2C->ICR = I2C_ICR_STOPCF;
        i2c->state = I2C_STATE_READY;
      }
    }
  }
  else if (i2c->state == I2C_STATE_SLAVE_TRANSMIT)
  {
    if (i2c_isr & I2C_ISR_ADDR)
    {
      dumpState("Transmit terminated by address match");
      I2C->CR1 &= ~(I2C_CR1_TXIE | I2C_CR1_NACKIE | I2C_CR1_STOPIE);
      if (i2c_isr & I2C_ISR_DIR)
      {
        debugPrintln("Address match, slave transmit");
        I2C->CR1 |= (I2C_CR1_TXIE | I2C_CR1_NACKIE | I2C_CR1_STOPIE);
        I2C->ISR |= I2C_ISR_TXE;
        I2C->ICR = I2C_ICR_ADDRCF;
        i2c->state = I2C_STATE_SLAVE_TRANSMIT;
      }
      else
      {
        debugPrintln("Address match, slave receive");
        I2C->CR1 |= (I2C_CR1_RXIE | I2C_CR1_STOPIE);
        I2C->ICR = I2C_ICR_ADDRCF;
        i2c->state = I2C_STATE_SLAVE_RECEIVE;
      }
    }
    else if (i2c_isr & I2C_ISR_NACKF)
    {
      dumpState("Transmit terminated by nack");
      I2C->CR1 &= ~(I2C_CR1_TXIE | I2C_CR1_NACKIE | I2C_CR1_STOPIE);
      I2C->ICR = (I2C_ICR_NACKCF | I2C_ICR_STOPCF);
      i2c->state = I2C_STATE_READY;
    }
    else if (i2c_isr & I2C_ISR_STOPF)
    {
      dumpState("Transmit terminated by stop");
      I2C->CR1 &= ~(I2C_CR1_TXIE | I2C_CR1_NACKIE | I2C_CR1_STOPIE);
      I2C->ICR = (I2C_ICR_NACKCF | I2C_ICR_STOPCF);
      i2c->state = I2C_STATE_READY;
    }
    else if (i2c_isr & I2C_ISR_TXIS)
    {
      debugPrintln("Transmit byte");
      if (cacheStale)
      {
        uint8_t value;
        switch (lastRegister)
        {
          case PRODUCT_ID_CMD:
            value = productId;
            break;
          case CP_PRODUCT_ID_CMD:
            //Serial.println("CP_PRODUCT_ID");
            value = CP_PRODUCT_ID;
            break;
          case REVISION_ID_CMD:
            value = revisionId;
            break;
          case CP_REVISION_ID_CMD:
            value = CP_REVISION_ID;
            break;
          case LEDSTATUS_CMD:
            value = ledStatus;
            break;
          case READ_RELATIVE_CMD:
            cached = last;
            cached.calcCrc();
            cachedBufferCount = sizeof(cached);
            memcpy(cachedBuffer, &cached, cachedBufferCount);
            cachedBufferPtr = cachedBuffer;
            value = *cachedBufferPtr++;
            break;
          case REREAD_RELATIVE_CMD:
            cachedBufferCount = sizeof(cached);
            memcpy(cachedBuffer, &cached, cachedBufferCount);
            cachedBufferPtr = cachedBuffer;
            value = *cachedBufferPtr++;
            break;
          case READ_ABSOLUTE_CMD:
            absolute.calcCrc();
            cachedBufferCount = sizeof(absolute);
            memcpy(cachedBuffer, &absolute, cachedBufferCount);
            cachedBufferPtr = cachedBuffer;
            value = *cachedBufferPtr++;
            break;
          default:
            value = 0x00;
            break;
        }
        cachedValue = value;
        cacheStale = false;
        i2cState = STATE_WAITING_FOR_REGISTER;
      } else {
        uint8_t value;
        switch (lastRegister)
        {
          case READ_RELATIVE_CMD:
          case REREAD_RELATIVE_CMD:
          case READ_ABSOLUTE_CMD:
            if (cachedBufferPtr < (cachedBuffer + cachedBufferCount)) {
              value = *cachedBufferPtr++;
            } else {
              value = 0x00;
            }
            break;
          default:
            value = 0x00;
            break;
        }
        cachedValue = value;
      }
      debugPrintln(cachedValue, HEX);
      I2C->TXDR = cachedValue;
      lastValue = cachedValue;
      lastValueSet = true;
    }
  }
}

int determineStateFromRegisterReceive(int lastRegister)
{
  switch (lastRegister) {
    case LEDSTATUS_CMD:
      return STATE_WAITING_FOR_READ_OR_DATA;
    case ZERO_ABSOLUTE_CMD:
    case RESET_CMD:
      return STATE_WAITING_FOR_DATA;
    default:
      return STATE_WAITING_FOR_READ;
  }
}

void setLEDStatus(uint8_t status)
{
  if (!ledOverwritten) {
    debugPrintln("Overwriting LEDs");
  }
  debugPrintln("setLEDStatus");
  ledOverwritten = true;
  //digitalWrite(WHITE_LED, status & 0x01 ? LED_ON : LED_OFF);
  digitalWrite(BLUE_LED, status & 0x02 ? LED_ON : LED_OFF);
  digitalWrite(GREEN_LED, status & 0x04 ? LED_ON : LED_OFF);
  digitalWrite(RED_LED, status & 0x08 ? LED_ON : LED_OFF);

  ledStatus = status;
}

void requestEvent() {
  requestCount++;
}

void receiveEvent(int bytesReceived) {
  receiveCount++;
}

void debugPrint(const char message[])
{
  if (settings.debugOn) {
    Serial.print(message);
  }
}

void debugPrintln(const char message[])
{
  if (settings.debugOn) {
    Serial.println(message);
  }
}

void debugPrintln(uint8_t v, int radix)
{
  if (settings.debugOn) {
    Serial.println(v, radix);
  }
}

void debugPrintln(char v, int radix)
{
  if (settings.debugOn) {
    Serial.println(v, radix);
  }
}

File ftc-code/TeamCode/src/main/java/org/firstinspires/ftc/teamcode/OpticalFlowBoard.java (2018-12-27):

package org.firstinspires.ftc.teamcode;

import com.qualcomm.robotcore.hardware.I2cAddr;
import com.qualcomm.robotcore.hardware.I2cDeviceSynch;
import com.qualcomm.robotcore.hardware.I2cDeviceSynchDevice;
import com.qualcomm.robotcore.hardware.configuration.annotations.DeviceProperties;
import com.qualcomm.robotcore.hardware.configuration.annotations.I2cDeviceType;
import com.qualcomm.robotcore.util.TypeConversion;

import org.firstinspires.ftc.teamcode.CCITTCrc16;
import org.firstinspires.ftc.teamcode.DbgLog;

import java.nio.ByteOrder;
import java.util.Arrays;
import java.util.EnumSet;

/**
 * Created by Cherry Pi on 12/27/2018.
 */
@DeviceProperties(name = "OpticalFlowBoard", description = "Optical Flow Board By Team 11411 Cherry Pi", xmlTag = "OpticalFlowBoard")
@I2cDeviceType
public class OpticalFlowBoard extends I2cDeviceSynchDevice<I2cDeviceSynch> {
    private static final byte EXPECTED_PRODUCT_ID = 0x49;
    private static final byte EXPECTED_CP_PRODUCT_ID = 0x42;

    private static final int WHITE_LED = 1;
    private static final int BLUE_LED = 2;
    private static final int GREEN_LED = 4;
    private static final int RED_LED = 8;

    private enum Register {
        PRODUCT_ID(0x00), // RO
        REVISION_ID(0x01), // RO
        CP_PRODUCT_ID(0x20), // RO
        CP_REVISION_ID(0x21), // RO
        LEDSTATUS(0x23), // R/W
        READ_RELATIVE(0x24), // RO
        REREAD_RELATIVE(0x25), // RO
        ZERO_ABSOLUTE(0x26), // WO
        READ_ABSOLUTE(0x27), // RO
        RESET(0x28); // WO

        public int bVal;

        Register(int bVal) {
            this.bVal = bVal;
        }
    }

    public class Delta {
        private int _x_offset;
        private int _y_offset;
        private int _timestamp;
        private int _x_overflow_count;
        private int _y_overflow_count;

        public Delta(int timestamp, short x_offset, short y_offset, byte overflow) {
            _timestamp = timestamp;
            _x_offset = x_offset;
            _y_offset = y_offset;
            _x_overflow_count = (overflow >> 4) & 0xf;
            _y_overflow_count = overflow & 0xf;
        }

        public int getXOffset() {
            return _x_offset;
        }

        public int getYOffset() {
            return _y_offset;
        }

        public int getTimestamp() {
            return _timestamp;
        }

        public int getXOverlowCount() {
            return _x_overflow_count;
        }

        public int getYOverflowCount() {
            return _y_overflow_count;
        }
    }

    public class Absolute {
        private int _x;
        private int _y;
        private int _timestamp;

        public Absolute(int timestamp, int x, int y) {
            _timestamp = timestamp;
            _x = x;
            _y = y;
        }

        public int getX() {
            return _x;
        }

        public int getY() {
            return _y;
        }

        public int getTimestamp() {
            return _timestamp;
        }
    }

    public enum LED {
        WHITE,
        BLUE,
        GREEN,
        RED
    }

    private static final I2cAddr ADDRESS_I2C_DEFAULT = I2cAddr.create7bit(0x29);

    public OpticalFlowBoard(I2cDeviceSynch i2cDeviceSynch) {
        super(i2cDeviceSynch, true);
        this.deviceClient.setI2cAddress(ADDRESS_I2C_DEFAULT);

        super.registerArmingStateCallback(false); // Deals with USB cables getting unplugged
        // Sensor starts off disengaged so we can change things like I2C address. Need to engage
        this.deviceClient.engage();
    }

    @Override
    protected boolean doInitialize() {
        I2cDeviceSynch.ReadWindow window = deviceClient.getReadWindow();
        if (window == null) {
            DbgLog.msg("Read window is null");
        } else {
            DbgLog.msg("Read window first %d count %d", window.getRegisterFirst(), window.getRegisterCount());
        }
        byte id = getProductIDRaw();
        if (id != EXPECTED_PRODUCT_ID) {
            DbgLog.error("Product id doesn't match. Expected 0x49 got %02x", id);
            return false;
        }
        id = getCPProductIDRaw();
        if (id != EXPECTED_CP_PRODUCT_ID) {
            DbgLog.error("CP Product id doesn't match. Expected 0x42 got %02x", id);
            return false;
        }

        return true;
    }

    @Override
    public Manufacturer getManufacturer() {
        return Manufacturer.Other;
    }

    @Override
    public String getDeviceName() {
        return "OpticalFlowBoard";
    }

    public byte getProductIDRaw() {
        DbgLog.msg("Reading product id");
        byte b = deviceClient.read8(Register.PRODUCT_ID.bVal);
        return b;
    }

    public byte getCPProductIDRaw() {
        DbgLog.msg("Reading cp product id");
        byte b = deviceClient.read8(Register.CP_PRODUCT_ID.bVal);
        return b;
    }

    public Delta readRelative() {
        byte[] bytes = deviceClient.read(Register.READ_RELATIVE.bVal, 11);
        return createDelta(bytes);
    }

    public Delta rereadRelative() {
        byte[] bytes = deviceClient.read(Register.REREAD_RELATIVE.bVal, 11);
        return createDelta(bytes);
    }

    public Absolute readAbsolute() {
        byte[] bytes = deviceClient.read(Register.READ_ABSOLUTE.bVal, 14);
        return createAbsolute(bytes);
    }

    public void zeroAbsolute() {
        deviceClient.write8(Register.ZERO_ABSOLUTE.bVal, 0);
    }

    public void reset() {
        deviceClient.write8(Register.RESET.bVal, 0);
    }

    public void setLedStatus(boolean whiteOn, boolean redOn, boolean greenOn, boolean blueOn) {
        byte status = 0;
        if (redOn) {
            status |= RED_LED;
        }
        if (greenOn) {
            status |= GREEN_LED;
        }
        if (blueOn) {
            status |= BLUE_LED;
        }
        if (whiteOn) {
            status |= WHITE_LED;
        }
        deviceClient.write8(Register.LEDSTATUS.bVal, status);
    }

    public void setLedStatus(EnumSet<LED> ledsOn) {
        setLedStatus(ledsOn.contains(LED.WHITE), ledsOn.contains(LED.RED), ledsOn.contains(LED.GREEN), ledsOn.contains(LED.BLUE));
    }

    public byte getLedStatusRaw() {
        return deviceClient.read8(Register.LEDSTATUS.bVal);
    }

    public EnumSet<LED> getLedStatus() {
        EnumSet<LED> result = EnumSet.noneOf(LED.class);
        byte status = getLedStatusRaw();
        if ((status & WHITE_LED) == WHITE_LED) {
            result.add(LED.WHITE);
        }
        if ((status & BLUE_LED) == BLUE_LED) {
            result.add(LED.BLUE);
        }
        if ((status & GREEN_LED) == GREEN_LED) {
            result.add(LED.GREEN);
        }
        if ((status & RED_LED) == RED_LED) {
            result.add(LED.RED);
        }

        return result;
    }
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

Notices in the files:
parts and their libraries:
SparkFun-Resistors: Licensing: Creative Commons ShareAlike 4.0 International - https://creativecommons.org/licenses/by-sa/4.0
